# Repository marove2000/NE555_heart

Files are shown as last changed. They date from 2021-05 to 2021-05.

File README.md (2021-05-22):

# Heart SMD NE555
24 LEDs forming a LED-Heart driven by a NE555 bistable vibrator. A LED-Light runs around the heart. The speed of the running LED-light can be modified by changeing some resistors.
This soldering Kit requires first experience in SMD-Soldering and is a very good practice for the size 0805.

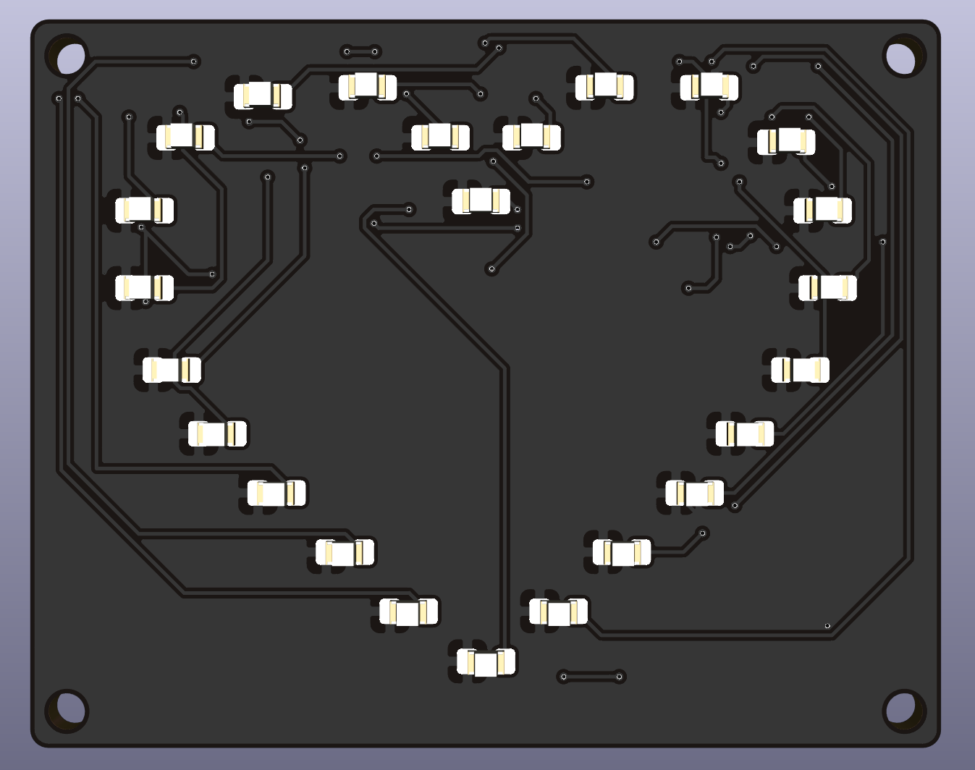
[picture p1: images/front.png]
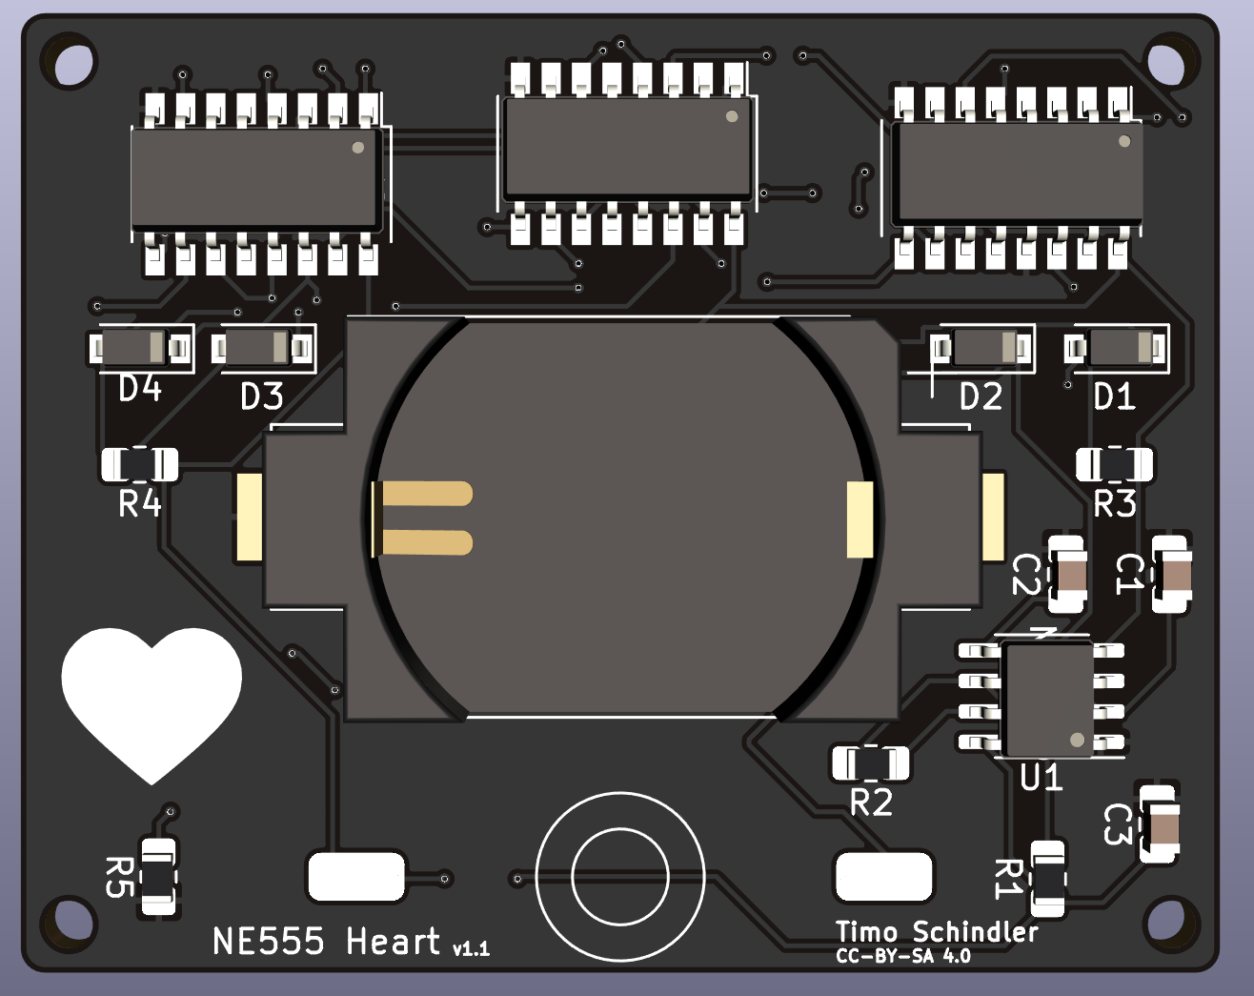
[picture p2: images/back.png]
 

- Status: **Complete**
- Difficulty: **3/5**

### Parts List

| Description |  Name  | Quantity |
|---|:---:|:---:|
| SMD LED 0805 red | D5-D28 | 24 |
| SMD Capacitor 1uF | C1 | 1 |
| SMD Capacitor 100n |  C2,C3 | 2 |
| SMD Diode 1N4007 |  D1-D4 | 4 |
| SMD Push Button | SW1  | 1 |
| SMD Resistor 0805 47k | R1 | 1 |
| SMD Resistor 0805 1k | R2 | 1 |
| SMD Resistor 0805 100k |  R3,R4 | 2 |
| SMD Resistor 0805 47R | R5 | 1 |
| NE555 SOIC-8 | U1 | 1 |
| CD4017 SOP-16 |  U2-U4 | 3 |
| CR2032 Battery Holder (SMD) | BT1  | 1 |
| CR2032 Battery (not included) | | 1 |

### Manual
You can find the manual and pictures of every step here: https://github.com/Binary-Kitchen/SolderingTutorial

### Copyright and Authorship

- Board: [CC-BY-SA 4.0](https://creativecommons.org/licenses/by-sa/4.0/) - Timo Schindler, Thomas Schmid
- CR2032 battery holder footprint: [CC-BY 4.0](https://creativecommons.org/licenses/by/4.0/) - Sparkfun (https://github.com/sparkfun/SparkFun-KiCad-Libraries)

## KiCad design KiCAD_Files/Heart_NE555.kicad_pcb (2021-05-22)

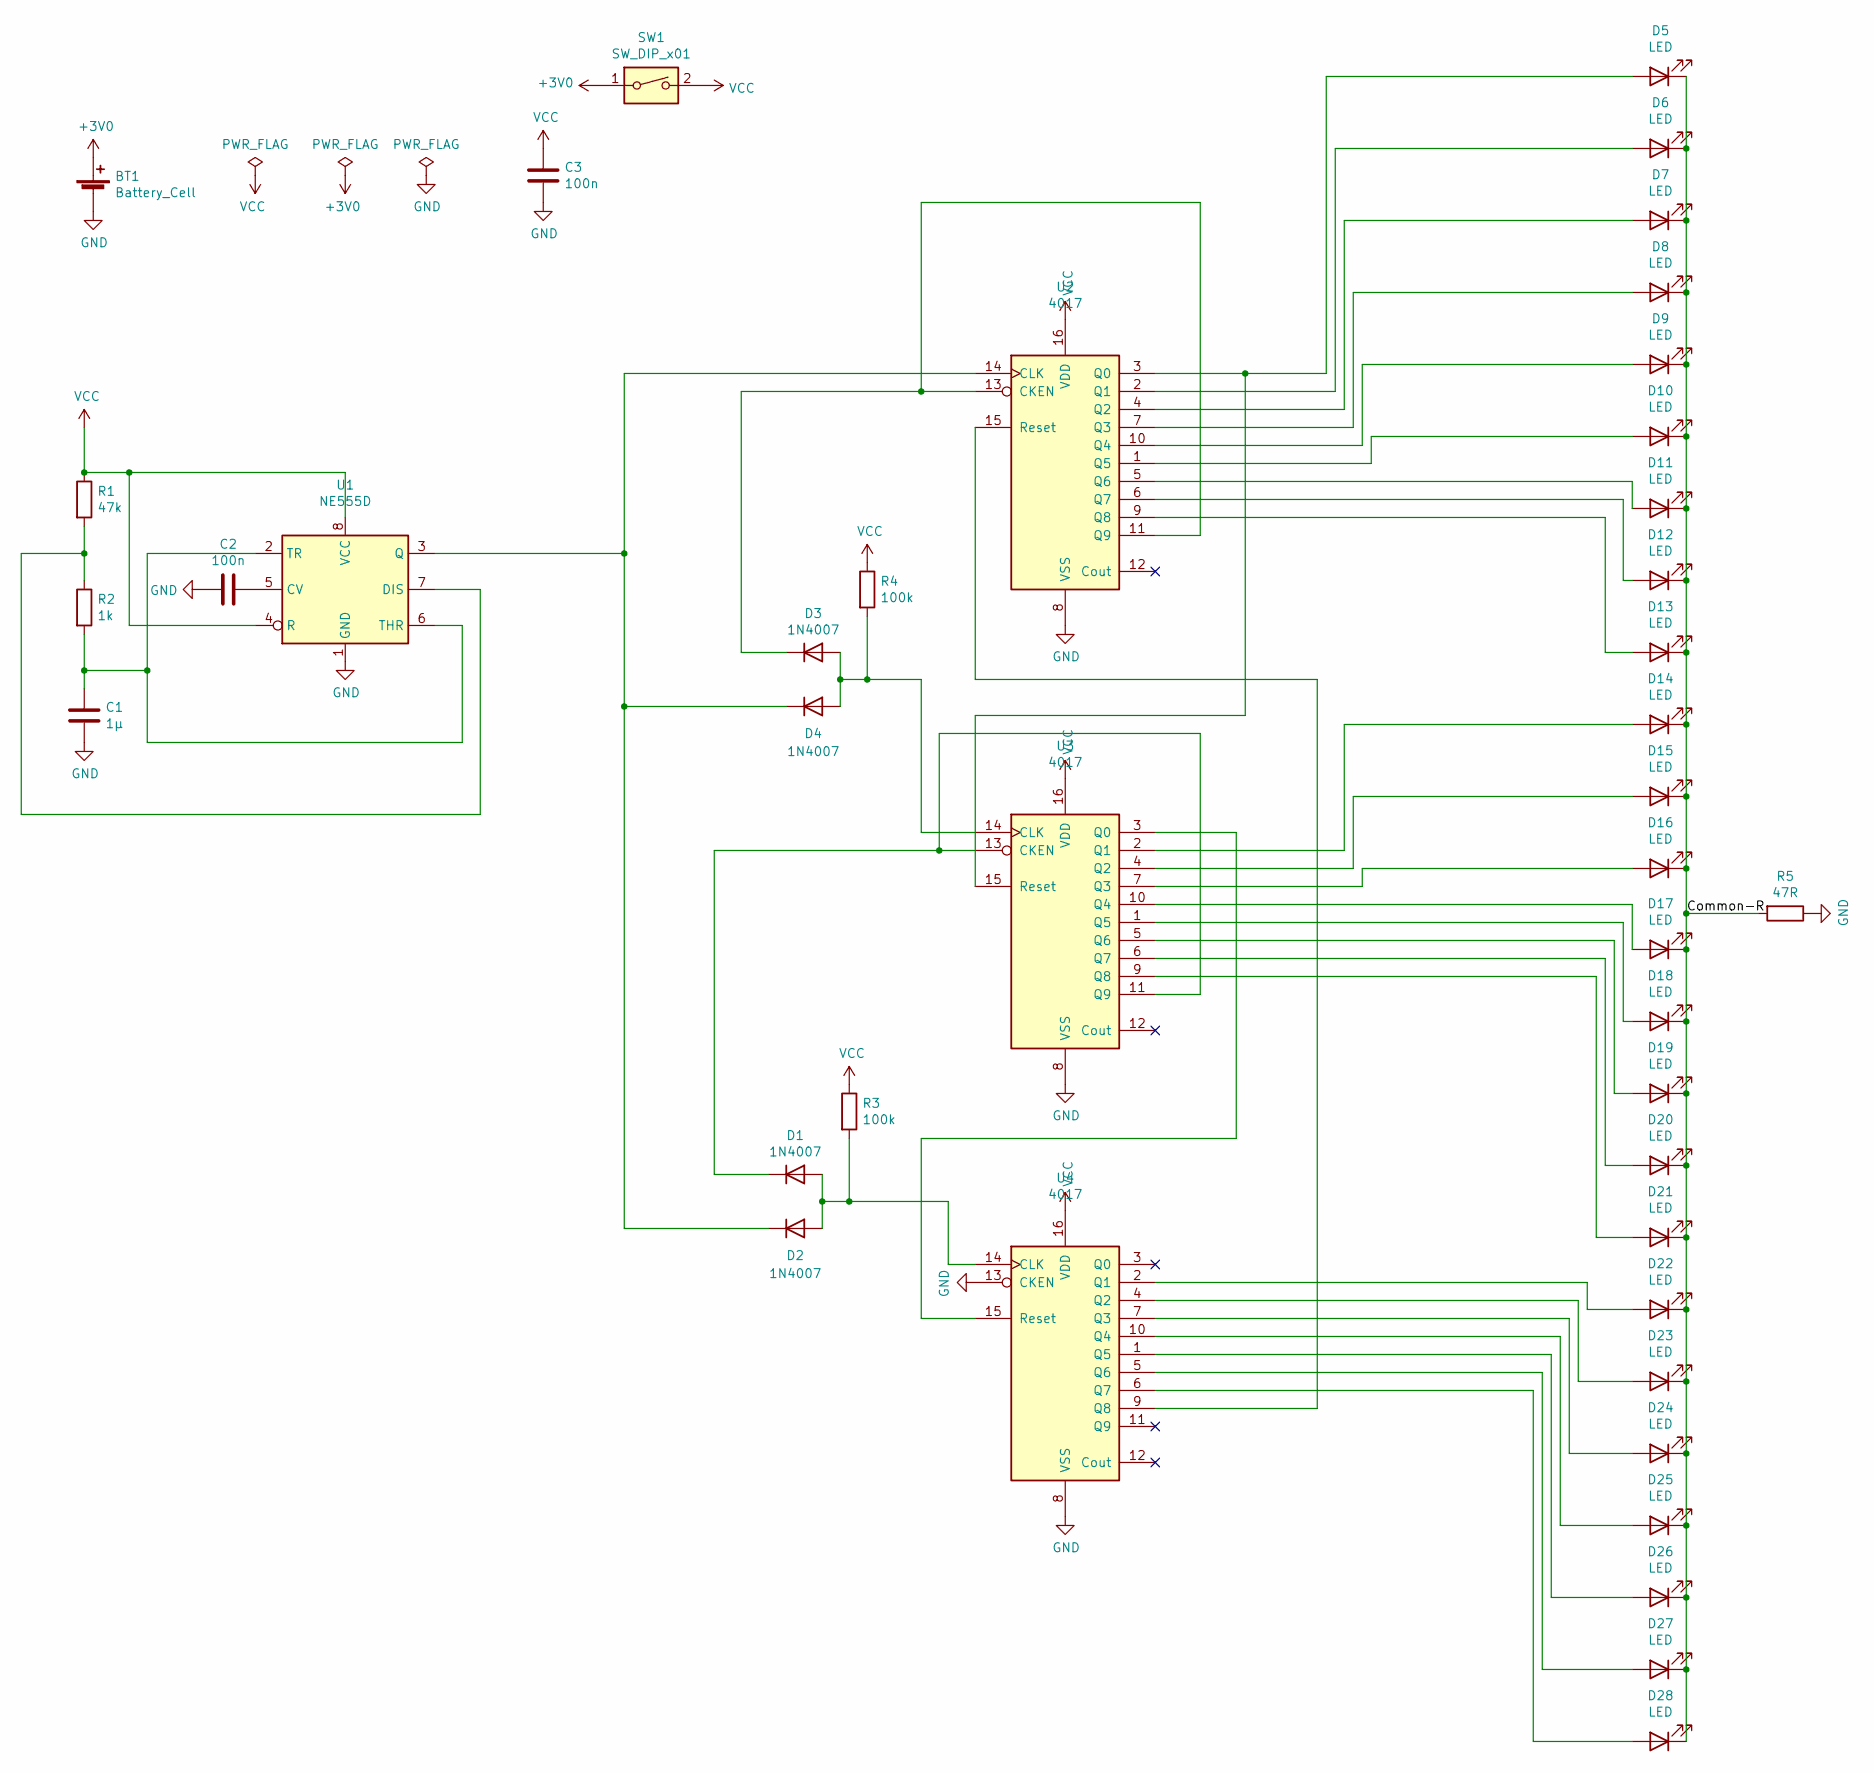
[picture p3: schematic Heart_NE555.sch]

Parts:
BT1: Battery_Cell; BatteryHolder_Keystone_1060_1x2032
C1: 1µ; C_0805_2012Metric_Pad1.18x1.45mm_HandSolder
C2, C3: 100n; C_0805_2012Metric_Pad1.18x1.45mm_HandSolder
D1, D2, D3, D4: 1N4007; D_SOD-123
D5, D6, D7, D8, D9, D10, D11, D12, D13, D14, D15, D16, D17, D18, D19, D20, D21, D22, D23, D24, D25, D26, D27, D28: LED; LED_0805_2012Metric_Pad1.15x1.40mm_HandSolder
R1: 47k; R_0805_2012Metric_Pad1.20x1.40mm_HandSolder
R2: 1k; R_0805_2012Metric_Pad1.20x1.40mm_HandSolder
R3, R4: 100k; R_0805_2012Metric_Pad1.20x1.40mm_HandSolder
R5: 47R; R_0805_2012Metric_Pad1.20x1.40mm_HandSolder
SW1: SW_DIP_x01; Push_Button
U1: NE555D; SOIC-8_3.9x4.9mm_P1.27mm
U2, U3, U4: 4017; SOP-16_4.4x10.4mm_P1.27mm

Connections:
+3V0: BT1.1 (+), SW1.1
/Common-R: D5.1 (K), D6.1 (K), D7.1 (K), D8.1 (K), D9.1 (K), D10.1 (K), D11.1 (K), D12.1 (K), D13.1 (K), D14.1 (K), D15.1 (K), D16.1 (K), D17.1 (K), D18.1 (K), D19.1 (K), D20.1 (K), D21.1 (K), D22.1 (K), D23.1 (K), D24.1 (K), D25.1 (K), D26.1 (K), D27.1 (K), D28.1 (K), R5.2
GND: BT1.2 (-), C1.2, C2.2, C3.2, R5.1, U1.1 (GND), U2.8 (VSS), U3.8 (VSS), U4.8 (VSS), U4.13 (CKEN)
unnamed: C1.1, R2.2, U1.2 (TR), U1.6 (THR)
unnamed: C2.1, U1.5 (CV)
unnamed: D1.1 (K), U3.11 (Q9), U3.13 (CKEN)
unnamed: D1.2 (A), D2.2 (A), R3.2, U4.14 (CLK)
unnamed: D2.1 (K), D4.1 (K), U1.3 (Q), U2.14 (CLK)
unnamed: D3.1 (K), U2.11 (Q9), U2.13 (CKEN)
unnamed: D3.2 (A), D4.2 (A), R4.2, U3.14 (CLK)
unnamed: D5.2 (A), U2.3 (Q0), U3.15 (Reset)
unnamed: D6.2 (A), U2.2 (Q1)
unnamed: D7.2 (A), U2.4 (Q2)
unnamed: D8.2 (A), U2.7 (Q3)
unnamed: D9.2 (A), U2.10 (Q4)
unnamed: D10.2 (A), U2.1 (Q5)
unnamed: D11.2 (A), U2.5 (Q6)
unnamed: D12.2 (A), U2.6 (Q7)
unnamed: D13.2 (A), U2.9 (Q8)
unnamed: D14.2 (A), U3.2 (Q1)
unnamed: D15.2 (A), U3.4 (Q2)
unnamed: D16.2 (A), U3.7 (Q3)
unnamed: D17.2 (A), U3.10 (Q4)
unnamed: D18.2 (A), U3.1 (Q5)
unnamed: D19.2 (A), U3.5 (Q6)
unnamed: D20.2 (A), U3.6 (Q7)
unnamed: D21.2 (A), U3.9 (Q8)
unnamed: D22.2 (A), U4.2 (Q1)
unnamed: D23.2 (A), U4.4 (Q2)
unnamed: D24.2 (A), U4.7 (Q3)
unnamed: D25.2 (A), U4.10 (Q4)
unnamed: D26.2 (A), U4.1 (Q5)
unnamed: D27.2 (A), U4.5 (Q6)
unnamed: D28.2 (A), U4.6 (Q7)
unnamed: R1.2, R2.1, U1.7 (DIS)
unnamed: U2.15 (Reset), U4.9 (Q8)
unnamed: U3.3 (Q0), U4.15 (Reset)
VCC: C3.1, R1.1, R3.1, R4.1, SW1.2, U1.4 (R), U1.8 (VCC), U2.16 (VDD), U3.16 (VDD), U4.16 (VDD)

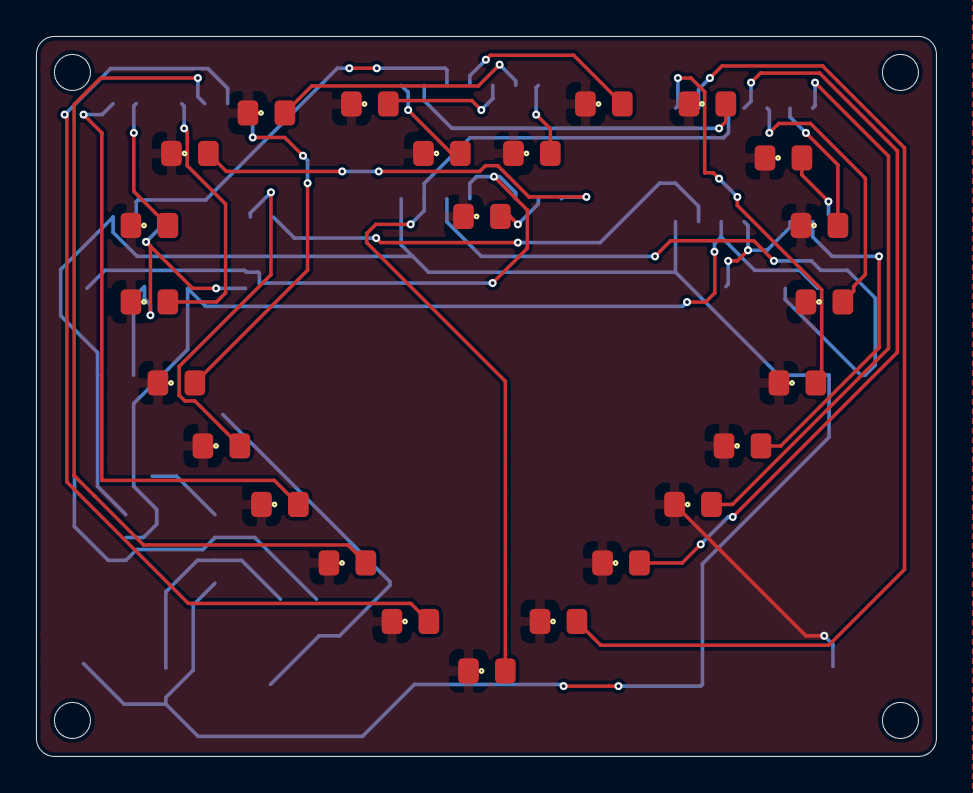
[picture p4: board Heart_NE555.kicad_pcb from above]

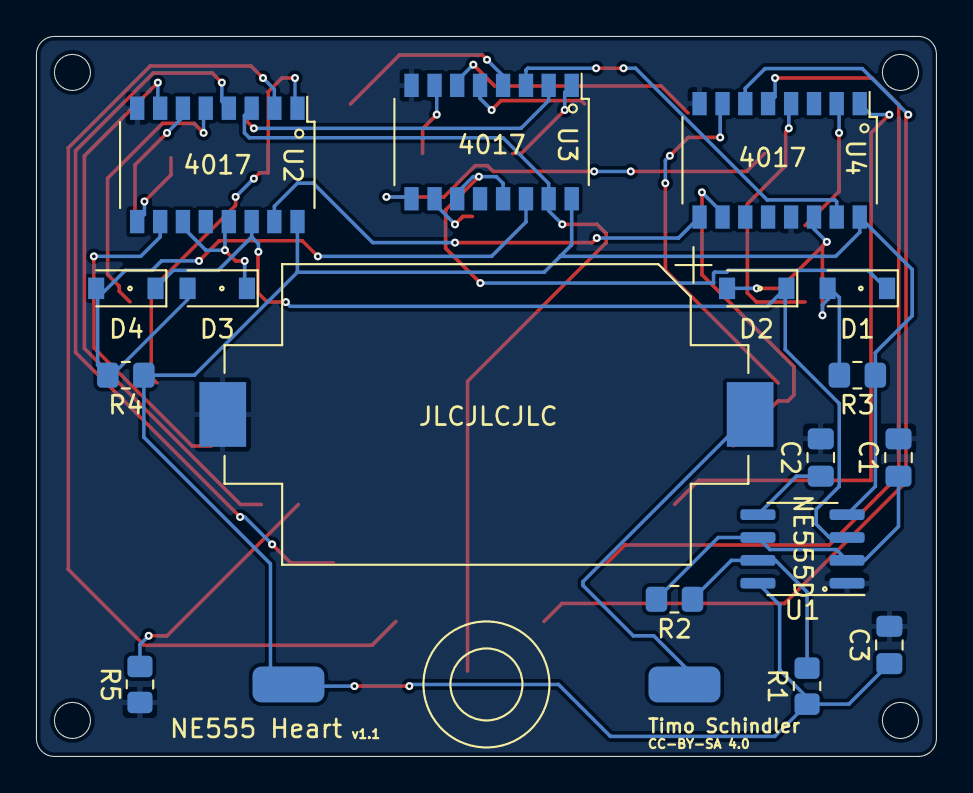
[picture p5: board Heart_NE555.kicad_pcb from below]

Board: 2 copper layers, 50.0 x 40.0 mm, 43 parts (18 on the bottom side), 38 nets.

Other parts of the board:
Ref**: Val**; heart_small

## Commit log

2021-01-21 inital commit
    [Heart_NE555.kicad_pcb, Heart_NE555.sch]
2021-01-23 fixed an naming error
    [Heart_NE555.kicad_pcb, Heart_NE555.sch]
2021-01-23 added gerber-files
    [Heart_NE555-B_Cu.gbr, Heart_NE555-B_Mask.gbr, Heart_NE555-B_Paste.gbr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]
2021-05-22 modified push button footprint
2021-05-22 changed footprints of diodes, fixed last-led-bug
    [Heart_NE555.kicad_pcb, Heart_NE555.sch]
2021-05-22 generated new gerberfiles
    [Heart_NE555-B_Cu.gbr, Heart_NE555-B_Mask.gbr, Heart_NE555-B_Paste.gbr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]
2021-05-22 increased version number, minor changes
    [Heart_NE555.kicad_pcb]
2021-05-22 generated new gerber fiels
    [Heart_NE555-B_Cu.gbr, Heart_NE555-B_Mask.gbr, Heart_NE555-B_Paste.gbr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]
2021-05-22 created readme with bom
